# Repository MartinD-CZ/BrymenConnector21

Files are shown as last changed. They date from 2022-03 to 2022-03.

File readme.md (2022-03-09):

# Brymen 867/869 adapter cable rev2.1
*see the article [here](http://embedblog.eu/?p=830) or the listing [here](https://www.tindie.com/products/martind/brymen-867869-adapter-cable/)*

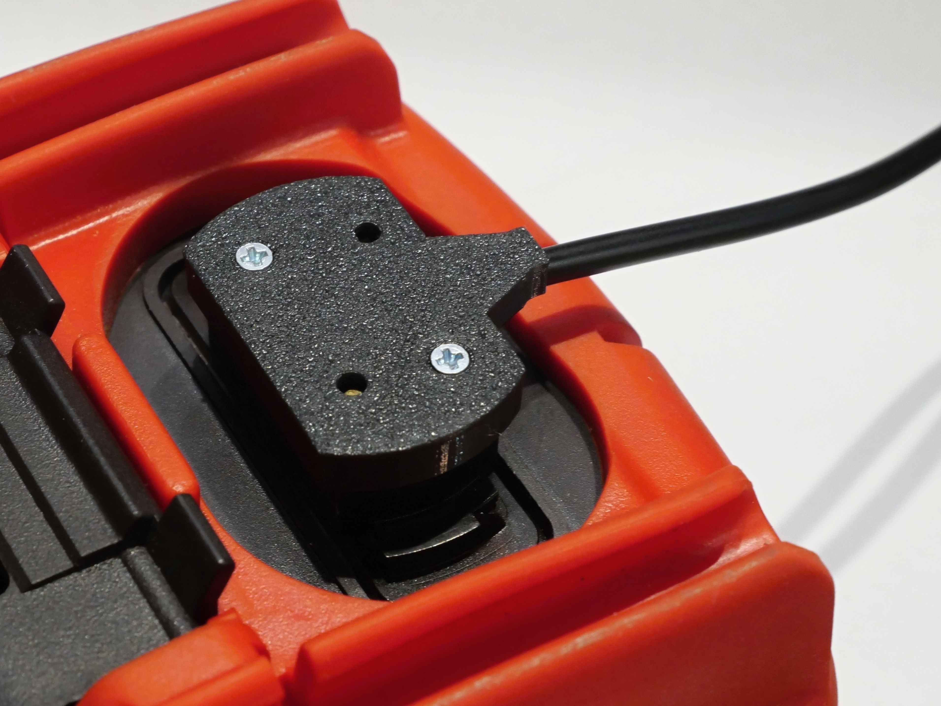
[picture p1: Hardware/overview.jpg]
A picture of the finished device


## Features
- reads data from Brymen 867/869 via infrared
- sends the measurements at 115200 baud via serial port
- output data rate and format adjustable (5 readings/s, 1 reading/s, single reading); settings are stored in EEPROM and remembered on next power up
- BOOT0 pin available as a button, so you can update the FW without disassembling the case
- activity LED

*Here's how the serial output looks:*
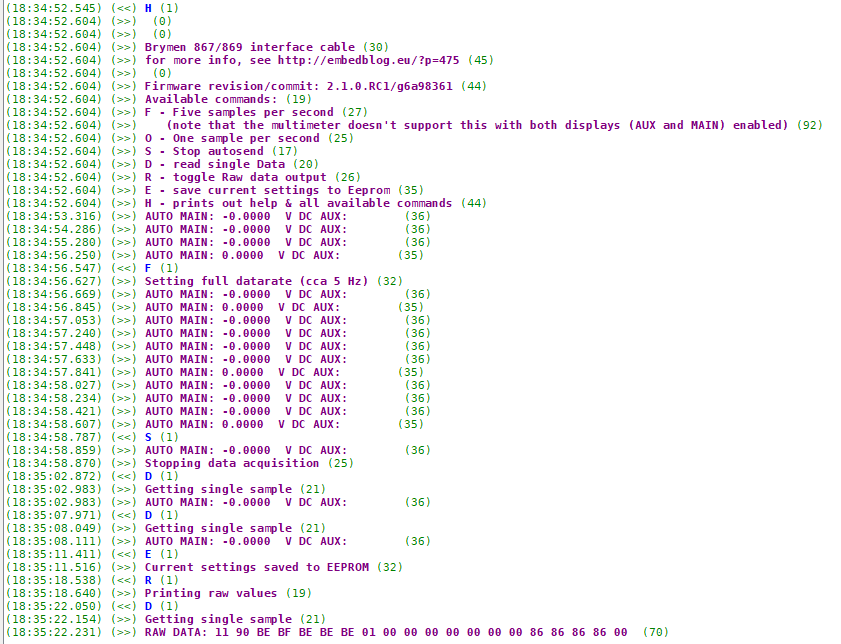
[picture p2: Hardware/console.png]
Console output


*If you are ordering it without the USB cable, here's how to connect it:*
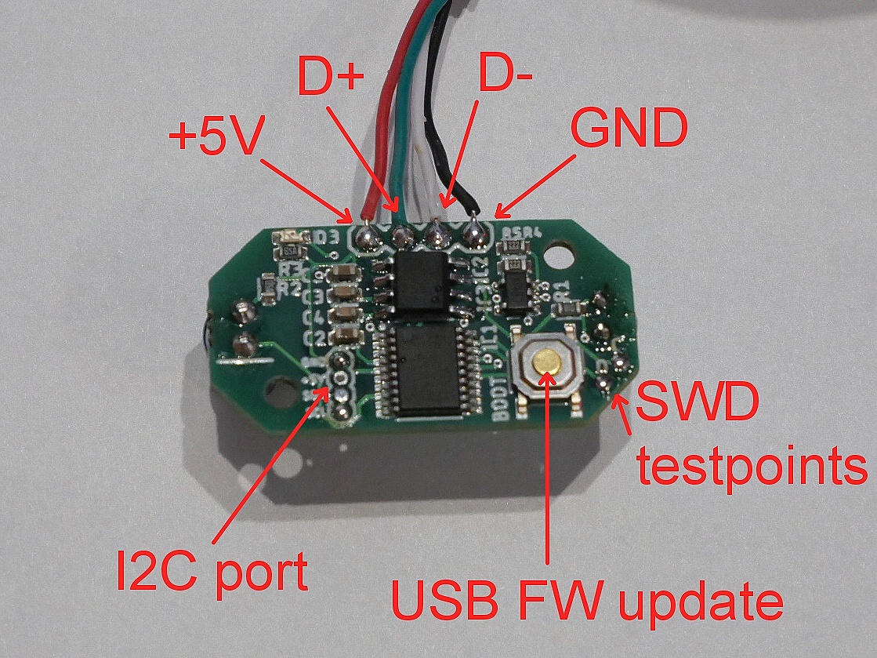
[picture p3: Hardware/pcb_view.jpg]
Connection diagram


*Note: revisions 1.x can be found [here](https://github.com/MartinD-CZ/brymen-867-interface-cable/blob/master/README.md), revision 2.0 can be found [here](https://github.com/MartinD-CZ/brymen-867-869-interface-cable-rev20).*

*And here's the schematic:*
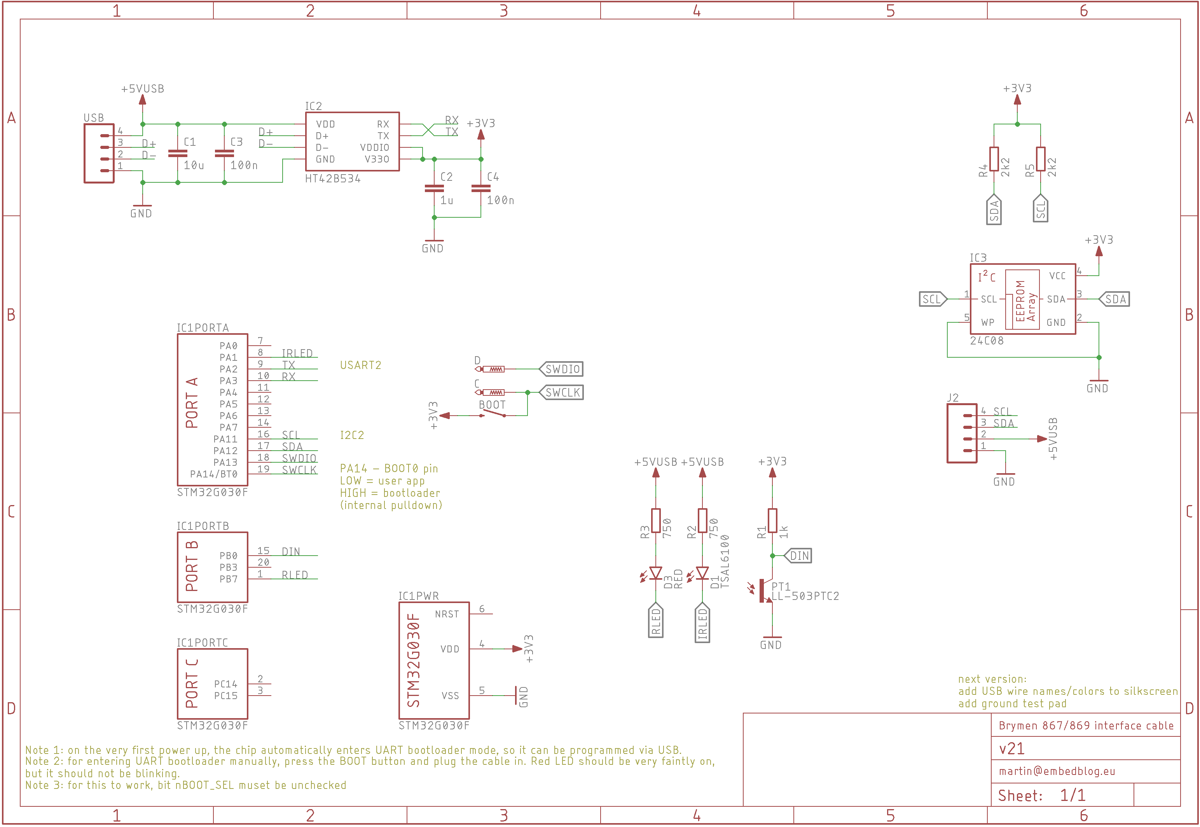
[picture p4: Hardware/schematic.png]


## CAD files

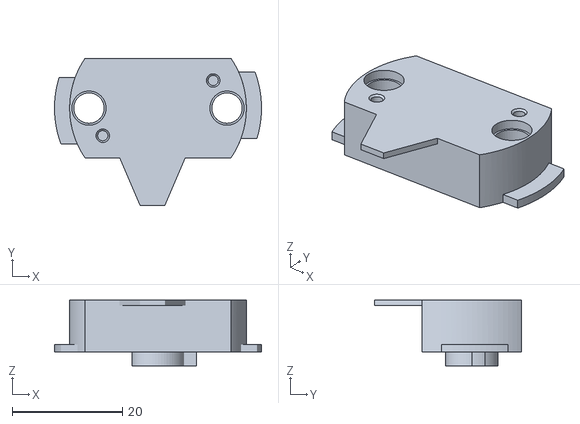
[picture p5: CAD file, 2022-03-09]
Hardware/case_bottom.stl
37.5 x 26.6 x 11.9

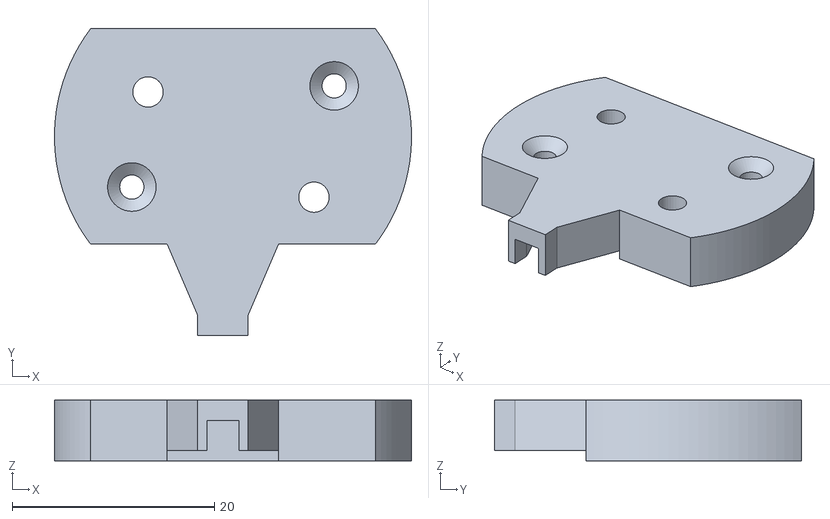
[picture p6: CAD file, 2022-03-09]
Hardware/case_top.stl
35.3 x 30.3 x 6.00

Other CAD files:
Hardware/case.f3d

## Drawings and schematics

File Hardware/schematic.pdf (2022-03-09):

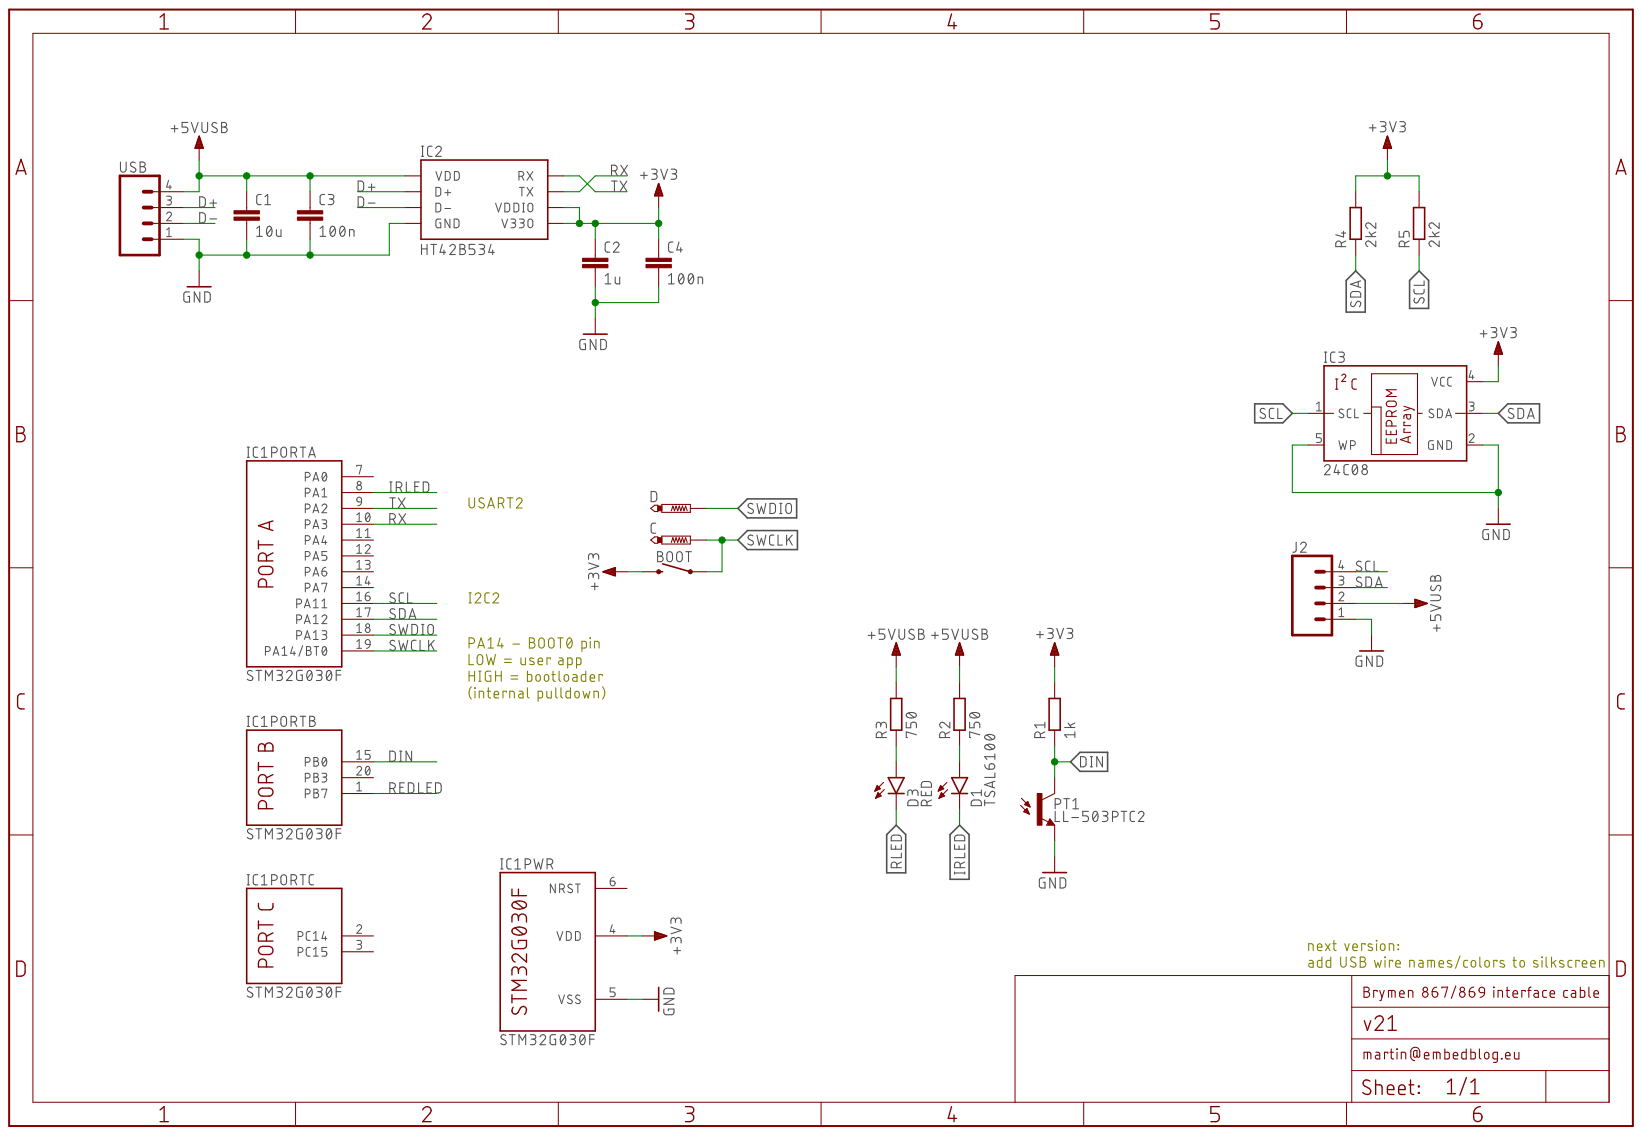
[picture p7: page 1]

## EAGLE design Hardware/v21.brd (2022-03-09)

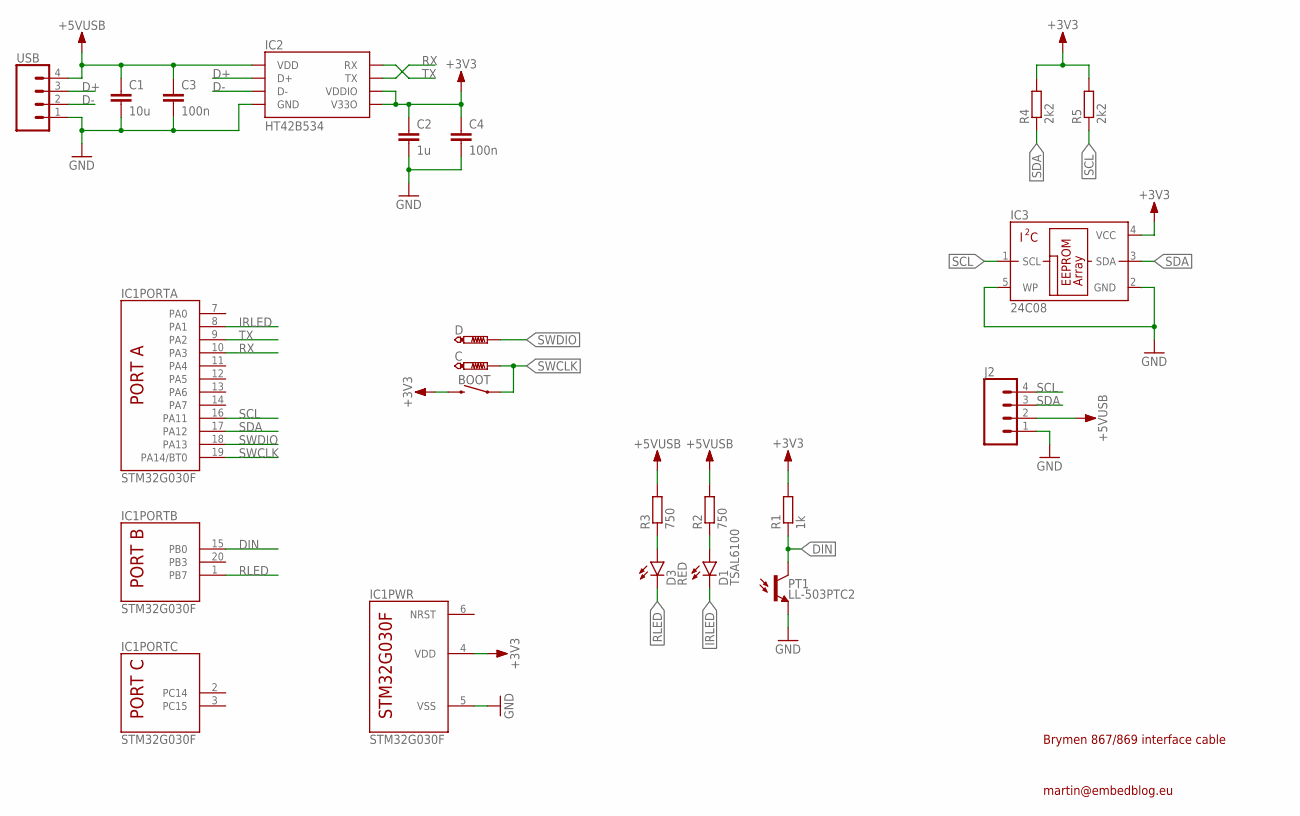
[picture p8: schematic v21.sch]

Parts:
BOOT: MOMENTARY-SWITCH-SPST-SMD-5.2MM; TACTILE_SWITCH_SMD_5.2MM
C: PTR1B1,27; B1,27
C1: 10u; C0603
C2: 1u; C0603
C3, C4: 100n; C0603
D: PTR1B1,27; B1,27
D1: TSAL6100; LED_5MM
D3: RED; LED-0603; LCSC# C2286
IC1: STM32G030F; TSSOP20
IC2: HT42B534; SOP8
IC3: 24C08; SOT23-5
J2: CONN_041.27MM; 1X04_1.27MM
PT1: LL-503PTC2; LED5MM
R1: 1k; R0603
R2, R3: 750; R0603
R4, R5: 2k2; R0603
USB: CONN_04; 1X04

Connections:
+3V3: BOOT.3 (2), C2.1, C4.1, IC1.4 (VDD), IC2.3 (VDDIO), IC2.8 (V33O), IC3.4 (VCC), R1.2, R4.2, R5.2
+5VUSB: C1.1, C3.1, IC2.7 (VDD), J2.2, R2.2, R3.2, USB.4
D+: IC2.5 (D+), USB.3
D-: IC2.6 (D-), USB.2
DIN: IC1.15 (PB0), PT1.K (C), R1.1
GND: C1.2, C2.2, C3.2, C4.2, IC1.5 (VSS), IC2.1 (GND), IC3.2 (GND), IC3.5 (WP), J2.1, PT1.A (E), USB.1
IRLED: D1.K (C), IC1.8 (PA1)
unnamed: D1.A, R2.1
unnamed: D3.A, R3.1
RLED: D3.C, IC1.1 (PB7)
RX: IC1.10 (PA3), IC2.2 (TX)
SCL: IC1.16 (PA11), IC3.1 (SCL), J2.4, R5.1
SDA: IC1.17 (PA12), IC3.3 (SDA), J2.3, R4.1
SWCLK: BOOT.1, C.TP, IC1.19 (PA14/BT0)
SWDIO: D.TP, IC1.18 (PA13)
TX: IC1.9 (PA2), IC2.4 (RX)

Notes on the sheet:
Brymen 867/869 interface cable
martin@embedblog.eu

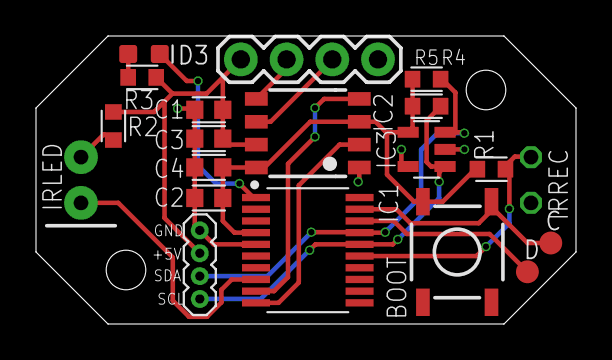
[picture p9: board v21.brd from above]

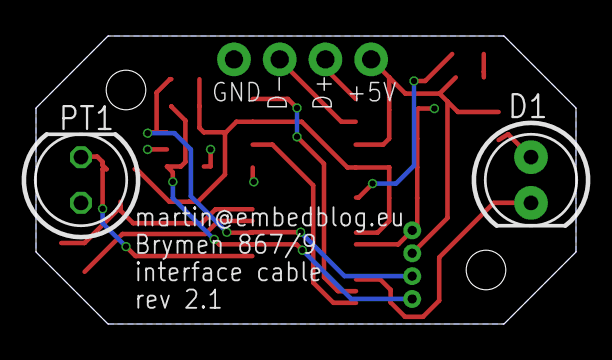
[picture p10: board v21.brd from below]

Board: 2 copper layers, 30.0 x 16.0 mm, 20 parts (2 on the bottom side), 16 nets.

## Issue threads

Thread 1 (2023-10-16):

No gerber files

godor2008, 2023-10-16:
Greetings! I have Brymen multimeter and wanted to order this board manufacture on JLCPCB, but I have not found gerber.zip in GitHub. Is it possible to add? And in what CAD was board developed?

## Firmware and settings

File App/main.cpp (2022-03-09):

/* main.cpp
 *
 * Created on: 7. 3. 2022
 * Author: Martin Danek, martin@embedblog.eu
 * baud 115200
 */

#include "main.h"

#include "comport.h"
#include "proj_conf.h"
#include "decoder.h"

#include "eeprom24.h"
#include "custom_assert.h"

extern I2C_HandleTypeDef hi2c2;
Eeprom24_08 eeprom{&hi2c2};

bool isSendingRawData;
Mode mode;			//current operating mode
Request request;	//requests from serial console

int main()
{
	HAL_Init();
	SystemClock_Config();

	MX_GPIO_Init();
	MX_DMA_Init();
	MX_TIM16_Init();
	MX_I2C2_Init();

	//startup blink
	for (uint_fast8_t i = 0; i < 6; i++)
	{
		HAL_GPIO_TogglePin(REDLED_GPIO_Port, REDLED_Pin);
		HAL_Delay(250);
	}

	HAL_Delay(500);
	comport::init();

	//init eeprom & load data
	ASSERT(eeprom.init());
	if (eeprom.readByte(EEPROM_VALID_ADDR) == EEPROM_VALID_FLAG)
	{
		uint8_t data = eeprom.readByte(EEPROM_CONF_ADDR);
		isSendingRawData = data >> 7;
		mode = (Mode)(data & 0b111);
		printf("Valid settings loaded from EEPROM\n");
	}

	uint32_t lastDataTick = 0;
	bool isReadoutRequested = false;
	while (true)
	{
		if ((mode == Mode::SEND_1HZ) && (HAL_GetTick() - lastDataTick >= 1000))
			isReadoutRequested = true;
		else if (mode == Mode::SEND_5HZ)
			isReadoutRequested = true;

		if (isReadoutRequested)
		{
			uint32_t measurementStart = HAL_GetTick();
			if (decoder::receiveMessage())
			{
				HAL_GPIO_WritePin(REDLED_GPIO_Port, REDLED_Pin, GPIO_PIN_RESET);
				lastDataTick = measurementStart;
				isReadoutRequested = false;
				decoder::processMessage();
				HAL_Delay(50);
				HAL_GPIO_WritePin(REDLED_GPIO_Port, REDLED_Pin, GPIO_PIN_SET);
			}
		}

		if (request != Request::NONE)
		{
			switch(request)
			{
				case Request::SET_MODE_5HZ:
					mode = Mode::SEND_5HZ;
					printf("Setting full datarate (cca 5 Hz)\n");
					break;
				case Request::SET_MODE_1HZ:
					mode = Mode::SEND_1HZ;
					printf("Setting datarate to 1 Hz\n");
					break;
				case Request::SET_MODE_STOP:
					mode = Mode::STOP;
					printf("Stopping data acquisition\n");
					break;
				case Request::REQUEST_DATA:
					mode = Mode::STOP;
					isReadoutRequested = true;
					printf("Getting single sample\n");
					break;
				case Request::SET_RAW:
					isSendingRawData = !isSendingRawData;
					printf("Printing %s values\n", isSendingRawData ? "raw" : "decoded");
					break;
				case Request::SAVE_EEPROM:
					eeprom.writeByte(EEPROM_VALID_ADDR, EEPROM_VALID_FLAG);
					eeprom.waitForReady();
					eeprom.writeByte(EEPROM_CONF_ADDR, (uint8_t)((uint8_t)mode | ((uint8_t)isSendingRawData << 7)));
					printf("Current settings saved to EEPROM\n");
					break;
				case Request::GET_HELP:
					comport::printHelp();
					break;
				default: break;
			}

			request = Request::NONE;
		}
	}
}

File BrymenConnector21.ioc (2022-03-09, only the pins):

Mcu.UserName=STM32G030F6Px
PA1.GPIO_Label=IRLED
PA1.Signal=GPIO_Output
PA13.Signal=SYS_SWDIO
PA14-BOOT0.Signal=SYS_SWCLK
PA2.Signal=USART2_TX
PA3.Signal=USART2_RX
PB0.GPIO_Label=DIN
PB0.Signal=GPIO_Input
PB7.GPIO_Label=REDLED
PB7.Signal=GPIO_Output

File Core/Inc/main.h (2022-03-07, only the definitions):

#define REDLED_Pin GPIO_PIN_7
#define REDLED_GPIO_Port GPIOB
#define IRLED_Pin GPIO_PIN_1
#define IRLED_GPIO_Port GPIOA
#define DIN_Pin GPIO_PIN_0
#define DIN_GPIO_Port GPIOB

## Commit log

2022-03-08 switched printf to static buffer
2022-03-09 fixed red led bug, moved order of init
    [main.cpp]
2022-03-09 updated timer enable to speed up clock
2022-03-09 added info about 5 Hz mode; improved delay between 1 Hz readings
2022-03-09 added hardware folder
    [case.f3d, case_bottom.stl, case_top.stl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]

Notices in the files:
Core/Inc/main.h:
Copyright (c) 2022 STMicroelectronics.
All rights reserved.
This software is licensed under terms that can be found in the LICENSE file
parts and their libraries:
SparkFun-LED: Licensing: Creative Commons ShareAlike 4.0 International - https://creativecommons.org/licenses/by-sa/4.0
